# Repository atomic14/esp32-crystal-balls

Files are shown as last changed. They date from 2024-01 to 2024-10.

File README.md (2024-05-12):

# Look At My Shiny Crystal Balls!

This PCB is now supporting two of my projects: [Crystal Balls](https://www.youtube.com/watch?v=1-Rm0mgg2RI) and my [Flame Lamp](https://youtu.be/qe_sFo2qRoI).

Absolute Balls! (https://www.youtube.com/watch?v=1-Rm0mgg2RI)

Flame Lamp (https://www.youtube.com/watch?v=qe_sFo2qRoI)

I got some of these [crystal balls](https://s.click.aliexpress.com/e/_DDdvNqJ) from AliExpress for Christmas.

Crystal Balls

The base is pretty simple, it's just some LEDs and resistors connected to the 5v USB power supply.

So, I decided to make something a bit more sophisticated.

Schematic

It's based around an ESP32-S3-Mini which means it can run the popular WLED firmware.

It's a pretty compact PCB.

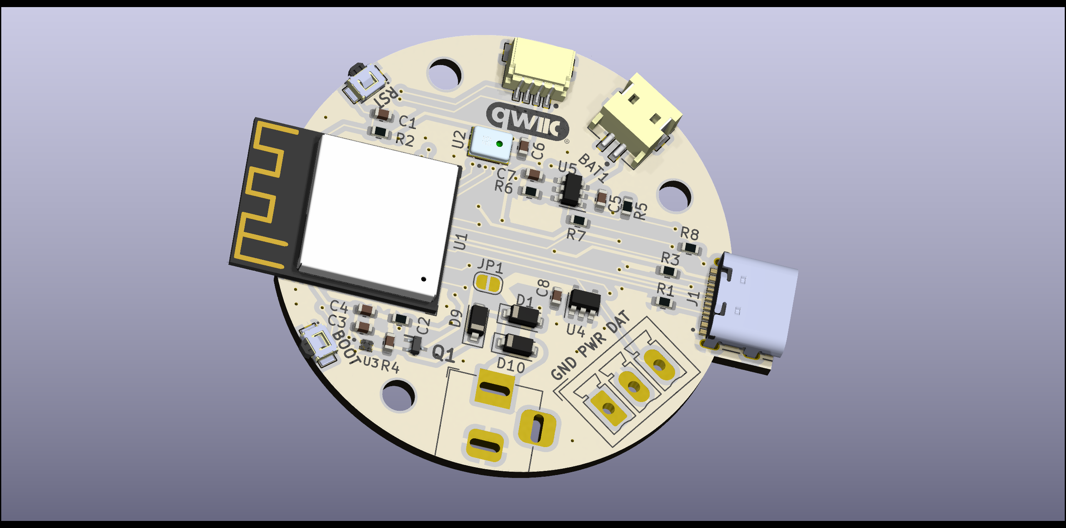
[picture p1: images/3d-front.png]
PCB Front


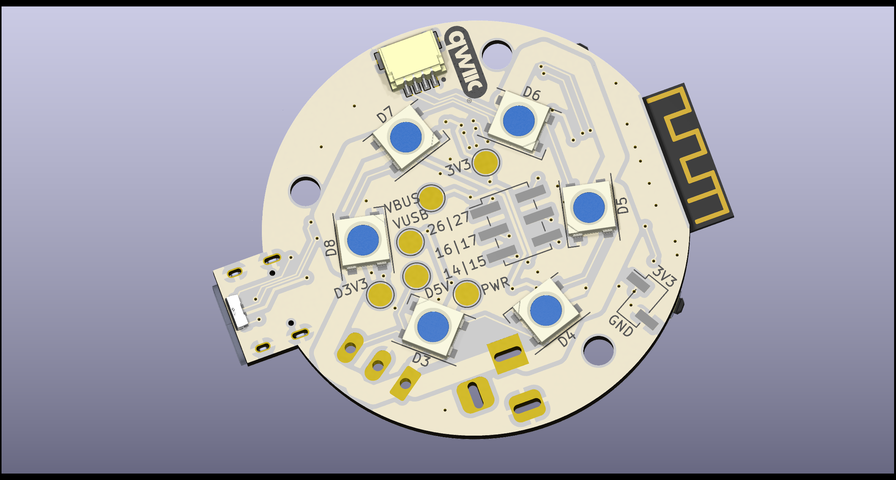
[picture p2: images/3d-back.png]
PCB Back


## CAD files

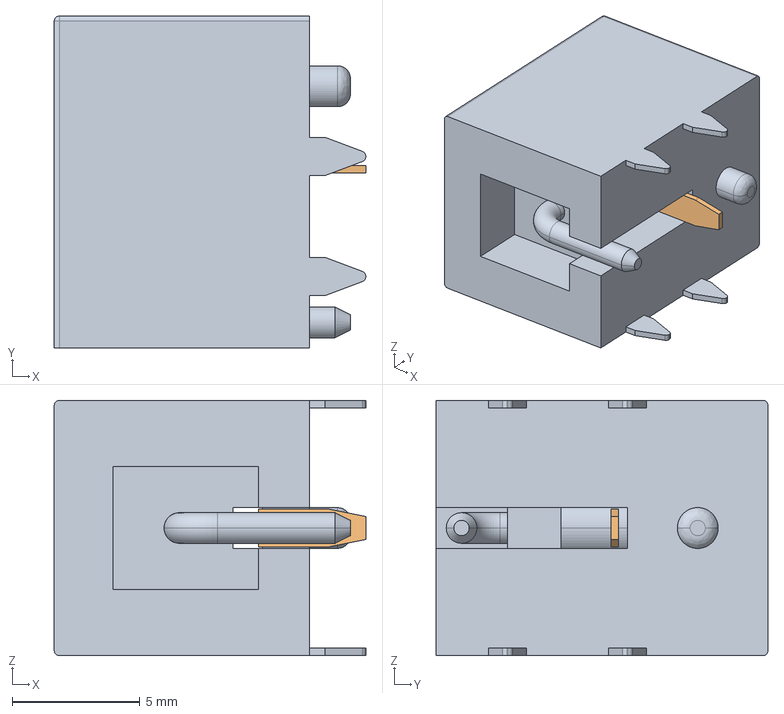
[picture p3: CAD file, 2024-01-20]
JACK_C_PC_10A_RA_R_/JACK-C-PC-10A-RA(R).stp
12.2 x 13.0 x 10.0 mm

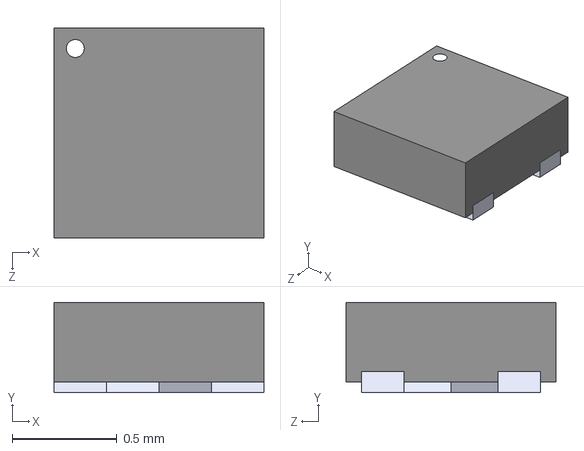
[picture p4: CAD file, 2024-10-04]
NCP167BMX330TBG/NCP167BMX330TBG.step
1.00 x 0.43 x 1.00 mm

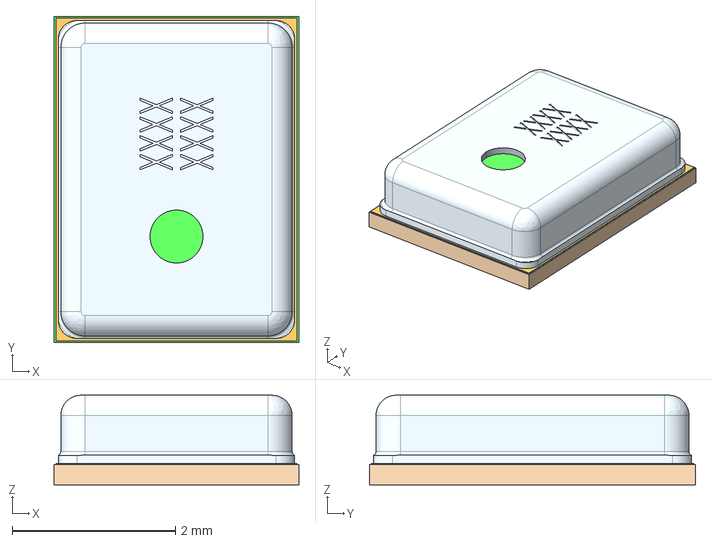
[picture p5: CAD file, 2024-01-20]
OWMMOD_403010A_S261F/OWMMOD-403010A-S261F.step
3.00 x 4.00 x 1.10 mm

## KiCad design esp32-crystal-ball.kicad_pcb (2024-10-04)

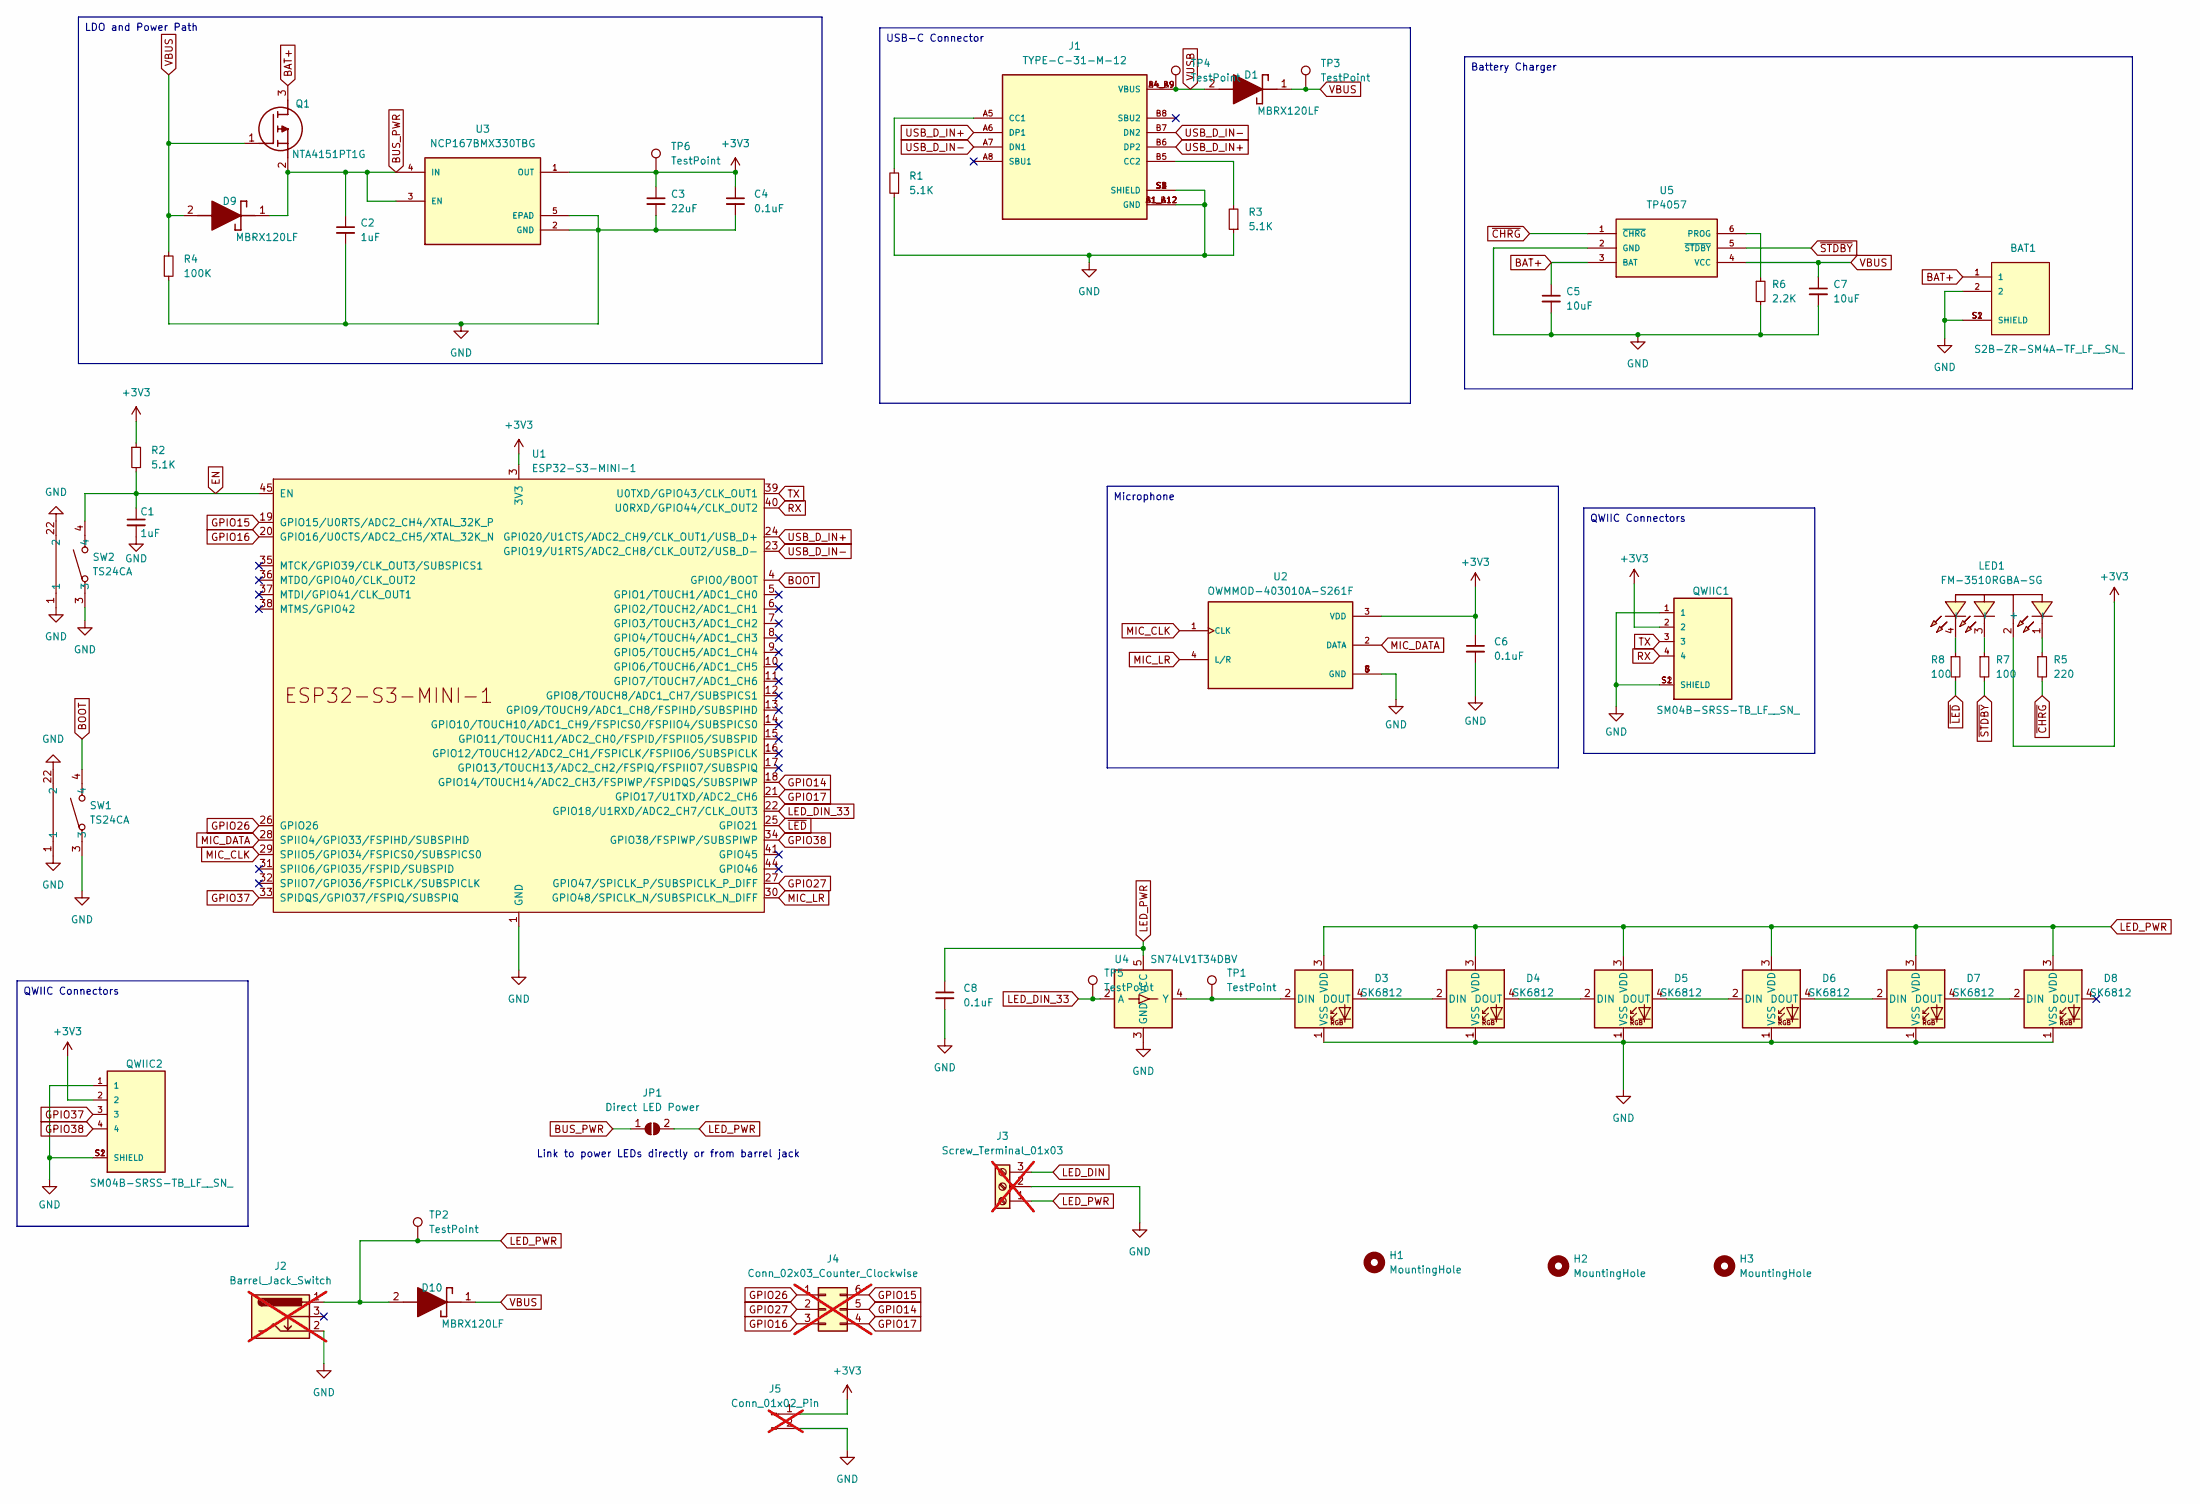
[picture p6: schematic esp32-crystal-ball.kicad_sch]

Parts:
BAT1: S2B-ZR-SM4A-TF_LF__SN_; JST_S2B-ZR-SM4A-TF_LF__SN_; PARTREV N/A
C1: 1uF; C_0603_1608Metric
C2: 1uF; C_0603_1608Metric; Mfg Part # test
C3: 22uF; C_0603_1608Metric
C4, C6, C8: 0.1uF; C_0603_1608Metric
C5, C7: 10uF; C_0603_1608Metric
D1, D9, D10: MBRX120LF; D_SOD-123
D3, D4, D5, D6, D7, D8: SK6812; LED_SK6812_PLCC4_5.0x5.0mm_P3.2mm
H1, H2, H3: MountingHole; MountingHole_3.2mm_M3
J1: TYPE-C-31-M-12; HRO_TYPE-C-31-M-12; PARTREV 2020.12.08
J2: Barrel_Jack_Switch; BarrelJack_Horizontal; not fitted
J3: Screw_Terminal_01x03; PhoenixContact_MCV_1,5_3-G-3.5_1x03_P3.50mm_Vertical; MPN MKDS 1/ 3-3,5; not fitted
J4: Conn_02x03_Counter_Clockwise; PinHeader_2x03_P2.54mm_Vertical_SMD; not fitted
J5: Conn_01x02_Pin; PinHeader_1x02_P2.54mm_Vertical_SMD_Pin1Left; not fitted
JP1: Direct LED Power; SolderJumper-2_P1.3mm_Open_RoundedPad1.0x1.5mm
LED1: FM-3510RGBA-SG; LED-SMD_FM-3510RGBA-SG; LCSC Part C727903
Q1: NTA4151PT1G; SOT50P160X90-3N; Mouser Part Number 863-NTA4151PT1G
QWIIC1, QWIIC2: SM04B-SRSS-TB_LF__SN_; JST_SM04B-SRSS-TB_LF__SN_
R1, R2, R3: 5.1K; R_0603_1608Metric
R4: 100K; R_0603_1608Metric
R5: 220; R_0603_1608Metric
R6: 2.2K; R_0603_1608Metric
R7, R8: 100; R_0603_1608Metric
SW1, SW2: TS24CA; SW-SMD_TS24CA; LCSC Part C393942
TP1, TP2, TP3, TP4, TP5, TP6: TestPoint; TestPoint_Pad_D2.5mm
U1: ESP32-S3-MINI-1
U2: OWMMOD-403010A-S261F; MIC_OWMMOD-403010A-S261F; PARTREV 00; DigiKey_Part_Number 3949-OWMMOD-403010A-S261F-ND
U3: NCP167BMX330TBG; VREG_NCP167BMX330TBG; PARTREV 5
U4: SN74LV1T34DBV; SOT-23-5
U5: TP4057; SOT-23-6

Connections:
+3V3: C3.1, C4.1, C6.1, J5.1, LED1.2 (+), QWIIC1.2, QWIIC2.2, R2.1, TP6.1, U1.3 (3V3), U2.3 (VDD), U3.1 (OUT)
BAT+: BAT1.1, C5.1, Q1.3 (D), U5.3 (BAT)
BOOT: SW1.4, U1.4 (GPIO0/BOOT); also elsewhere on the board
BUS_PWR: C2.1, D9.1 (K), JP1.1 (A), Q1.2 (S), U3.3 (EN), U3.4 (IN)
EN: C1.1, R2.2, U1.45 (EN); also elsewhere on the board
GND: BAT1.2, BAT1.S1 (SHIELD), BAT1.S2 (SHIELD), C1.2, C2.2, C3.2, C4.2, C5.2, C6.2, C7.2, C8.2, D3.1 (VSS), D4.1 (VSS), D5.1 (VSS), D6.1 (VSS), D7.1 (VSS), D8.1 (VSS), J1.A1_B12 (GND), J1.B1_A12 (GND), J1.S1 (SHIELD), J1.S2 (SHIELD), J1.S3 (SHIELD), J1.S4 (SHIELD), J2.2, J3.2, J5.2, QWIIC1.1, QWIIC1.S1 (SHIELD), QWIIC1.S2 (SHIELD), QWIIC2.1, QWIIC2.S1 (SHIELD), QWIIC2.S2 (SHIELD), R1.1, R3.1, R4.2, R6.2, U1.1 (GND), U1.2 (GND), U1.42 (GND), U1.43 (GND), U1.46 (GND), U1.47 (GND), U1.48 (GND), U1.49 (GND), U1.50 (GND), U1.51 (GND), U1.52 (GND), U1.53 (GND), U1.54 (GND), U1.55 (GND), U1.56 (GND), U1.57 (GND), U1.58 (GND), U1.59 (GND), U1.60 (GND), U1.61 (GND), U1.62 (GND), U1.63 (GND), U1.64 (GND), U1.65 (GND), U2.5 (GND), U2.6 (GND), U2.7 (GND), U2.8 (GND), U3.2 (GND), U3.5 (EPAD), U4.3 (GND), U5.2 (GND); also elsewhere on the board
GPIO14: J4.5, U1.18 (GPIO14/TOUCH14/ADC2_CH3/FSPIWP/FSPIDQS/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)
GPIO15: J4.6, U1.19 (GPIO15/U0RTS/ADC2_CH4/XTAL_32K_P)
GPIO16: J4.3, U1.20 (GPIO16/U0CTS/ADC2_CH5/XTAL_32K_N)
GPIO17: J4.4, U1.21 (GPIO17/U1TXD/ADC2_CH6)
GPIO26: J4.1, U1.26 (GPIO26)
GPIO27: J4.2, U1.27 (GPIO47/SPICLK_P/SUBSPICLK_P_DIFF)
GPIO37: QWIIC2.3, U1.33 (SPIDQS/GPIO37/FSPIQ/SUBSPIQ)
GPIO38: QWIIC2.4, U1.34 (GPIO38/FSPIWP/SUBSPIWP)
LED_DIN_33: TP5.1, U1.22 (GPIO18/U1RXD/ADC2_CH7/CLK_OUT3), U4.2 (A)
LED_PWR: C8.1, D3.3 (VDD), D4.3 (VDD), D5.3 (VDD), D6.3 (VDD), D7.3 (VDD), D8.3 (VDD), D10.2 (A), J2.1, J3.1, JP1.2 (B), TP2.1, U4.5 (VCC)
MIC_CLK: U1.29 (SPIIO5/GPIO34/FSPICS0/SUBSPICS0), U2.1 (CLK)
MIC_DATA: U1.28 (SPIIO4/GPIO33/FSPIHD/SUBSPIHD), U2.2 (DATA)
MIC_LR: U1.30 (GPIO48/SPICLK_N/SUBSPICLK_N_DIFF), U2.4 (L/R)
unnamed: D3.4 (DOUT), D4.2 (DIN)
unnamed: D4.4 (DOUT), D5.2 (DIN)
unnamed: D5.4 (DOUT), D6.2 (DIN)
unnamed: D6.4 (DOUT), D7.2 (DIN)
unnamed: D7.4 (DOUT), D8.2 (DIN)
unnamed: J1.A5 (CC1), R1.2
unnamed: J1.B5 (CC2), R3.2
unnamed: LED1.1 (-), R5.1
unnamed: LED1.3 (-), R7.1
unnamed: LED1.4 (-), R8.1
unnamed: R6.1, U5.6 (PROG)
RX: QWIIC1.4, U1.40 (U0RXD/GPIO44/CLK_OUT2)
TX: QWIIC1.3, U1.39 (U0TXD/GPIO43/CLK_OUT1)
USB_D_IN+: J1.A6 (DP1), J1.B6 (DP2), U1.24 (GPIO20/U1CTS/ADC2_CH9/CLK_OUT1/USB_D+)
USB_D_IN-: J1.A7 (DN1), J1.B7 (DN2), U1.23 (GPIO19/U1RTS/ADC2_CH8/CLK_OUT2/USB_D-)
VBUS: C7.1, D1.1 (K), D9.2 (A), D10.1 (K), Q1.1 (G), R4.1, TP3.1, U5.4 (VCC)
VUSB: D1.2 (A), J1.A4_B9 (VBUS), J1.B4_A9 (VBUS), TP4.1
~CHRG: R5.2, U5.1 (~CHRG)
~LED: R8.2, U1.25 (GPIO21)
~STDBY: R7.2, U5.5 (~STDBY)

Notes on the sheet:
QWIIC Connectors
LDO and Power Path
USB-C Connector
Microphone
Battery Charger
Link to power LEDs directly or from barrel jack

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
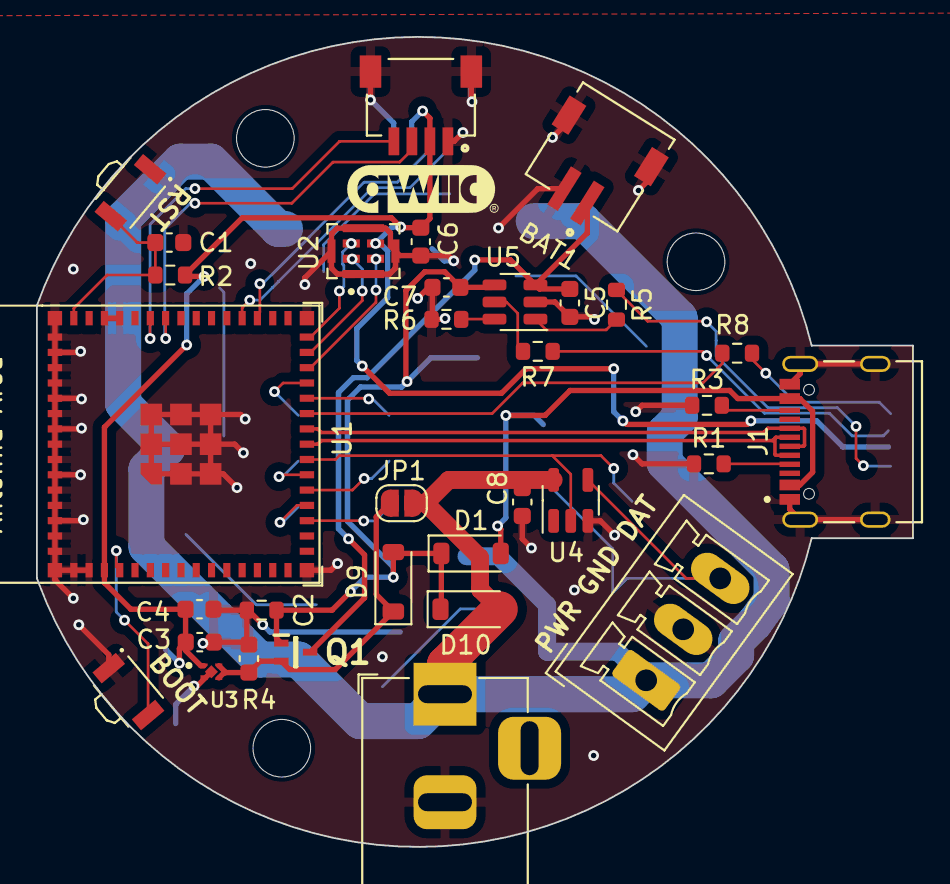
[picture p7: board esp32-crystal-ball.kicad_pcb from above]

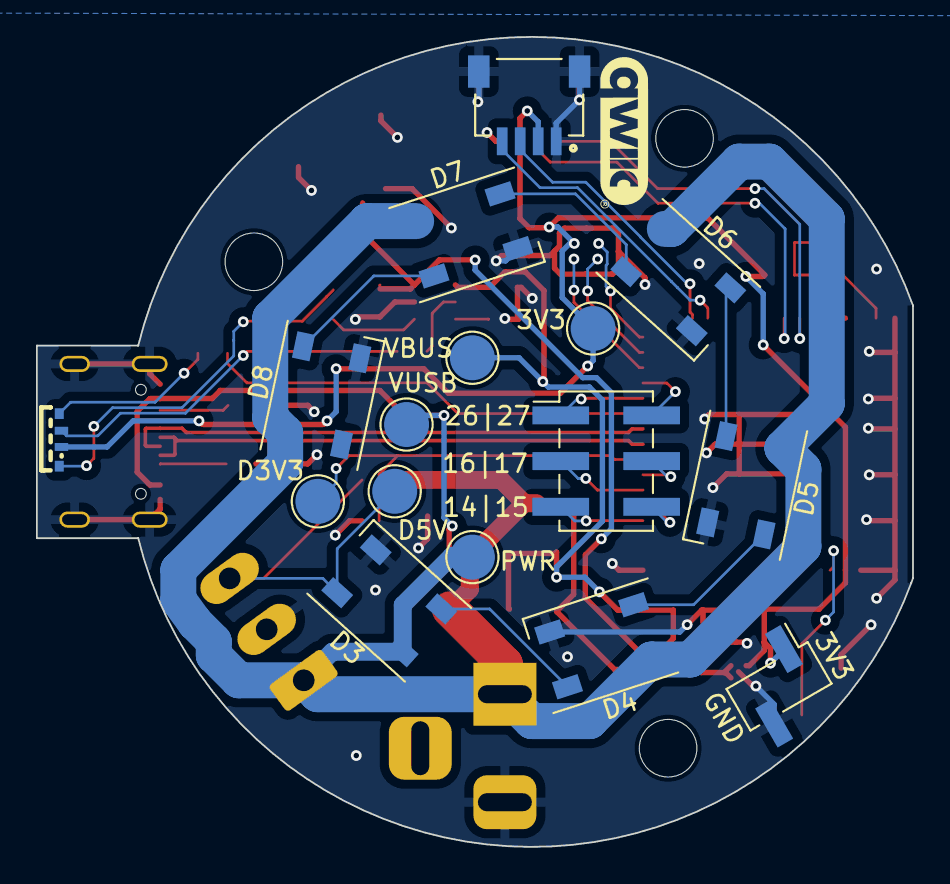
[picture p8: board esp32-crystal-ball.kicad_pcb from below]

Board: 2 copper layers, 48.7 x 45.0 mm, 52 parts (16 on the bottom side), 40 nets.

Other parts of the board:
BOOT1: B3U-3000P; SW_B3U-3000P
EN1: B3U-3000P; SW_B3U-3000P

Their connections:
BOOT: BOOT1.2; also elsewhere on the board
EN: EN1.2; also elsewhere on the board
GND: BOOT1.1, EN1.1; also elsewhere on the board

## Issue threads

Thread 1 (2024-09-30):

Probably not correct files

giorgosn, 2024-09-30:
I tried to reproduce the pcb in the pcbway and I got this message from the people there that the designs are probably wrong.
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

I have big exp on pcbs but from my kicad seems that there is no component there but the youtube videos seems to have something.
Not sure how to handle it.

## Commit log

2024-04-19 Adds images and README file.
    [esp32-crystal-ball.kicad_pcb, esp32-crystal-ball.kicad_sch]
2024-05-12 Fix silk screen
    [esp32-crystal-ball.kicad_pcb]
2024-10-04 Fixes voltage regulator footprint
    [NCP167BMX330TBG.step, esp32-crystal-ball.kicad_pcb, esp32-crystal-ball.kicad_sch]
